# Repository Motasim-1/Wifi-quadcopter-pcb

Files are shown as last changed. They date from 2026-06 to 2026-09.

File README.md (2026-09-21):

# WiFi-Controlled Quadcopter PCB Using ESP32

Custom PCB design for a WiFi-controlled quadcopter based on the ESP32 microcontroller. The board was designed in KiCad, assembled using solder paste and a reflow oven, and tested with four motor outputs controlled through a mobile app.

## Project overview

The goal of this project was to design a compact quadcopter control PCB that integrates the main electronics on a single board and reduces external wiring.

## Key features

- ESP32-based control board with built-in WiFi capability
- Custom quadcopter-shaped PCB designed in KiCad
- Four motor-control outputs using MOSFET driver stages
- USB interface for programming/debugging
- SMD assembly using solder paste and reflow oven
- Power verification and short-circuit testing after assembly
- Functional motor testing using mobile-app WiFi control

## Hardware design

The KiCad project is located in:

```text
hardware/kicad/
```

Included schematic sheets:

```text
my_drone.kicad_sch
mcu.kicad_sch
motor.kicad_sch
power.kicad_sch
usb.kicad_sch
imu.kicad_sch
```

The PCB layout file is:

```text
my_drone.kicad_pcb
```

## Figures

### KiCad 3D view

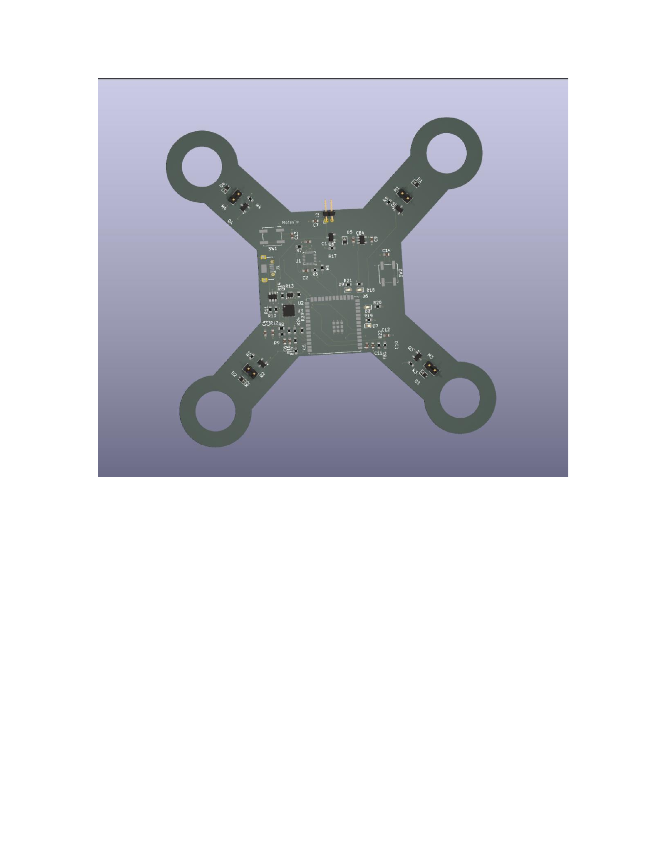
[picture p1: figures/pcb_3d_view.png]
PCB 3D view


### Assembled PCB

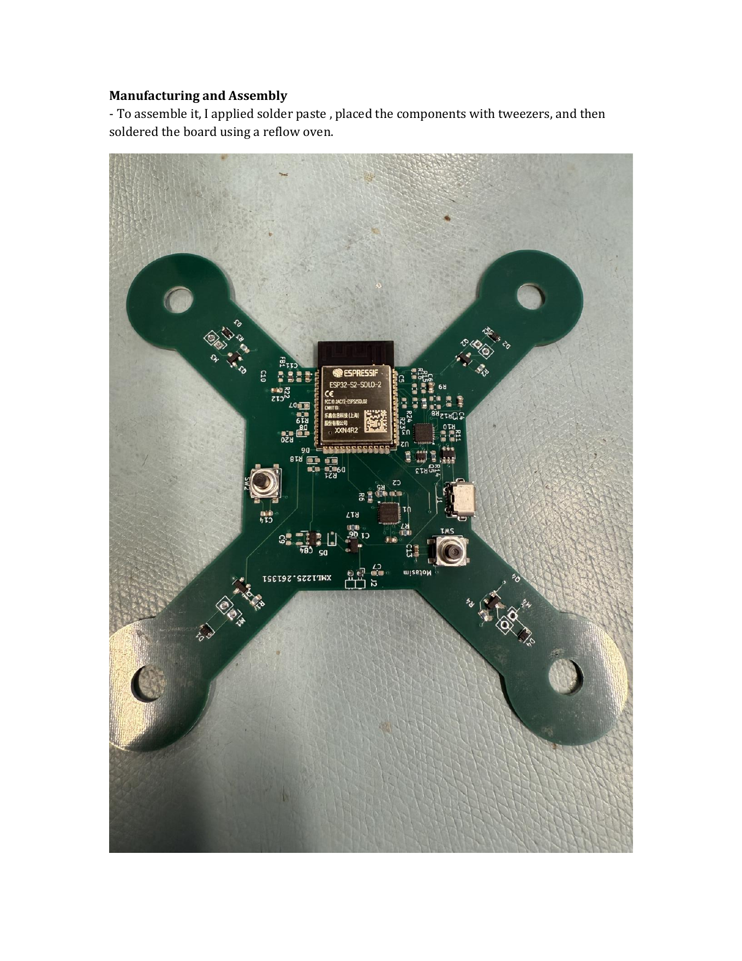
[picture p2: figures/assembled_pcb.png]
Assembled PCB


### Motor test setup

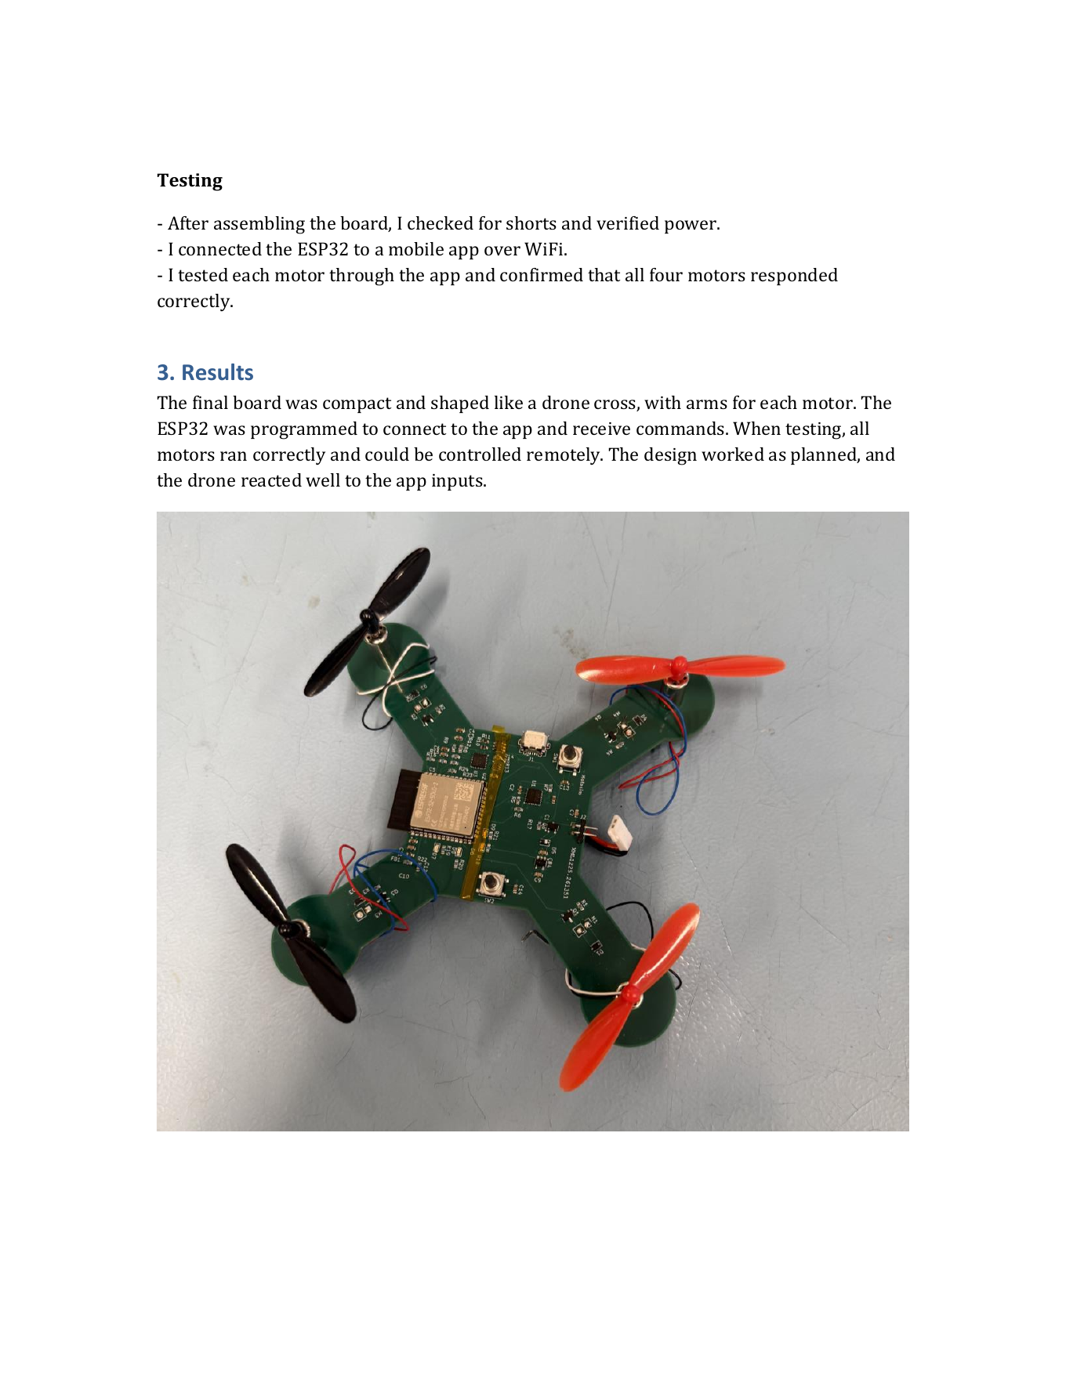
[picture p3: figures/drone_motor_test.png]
Motor test


## Tools and technologies

- KiCad
- ESP32
- PCB design
- SMD soldering
- Reflow soldering
- MOSFET motor switching
- WiFi-based control
- Hardware testing and troubleshooting

## Firmware note

The original motor-control setup was tested using an existing mobile-control framework. This repository focuses on the custom PCB hardware design, assembly and validation. 
## Repository structure

```text
wifi-controlled-quadcopter-pcb/
├── README.md
├── .gitignore
├── hardware/
│   └── kicad/
├── figures/
## Documentation

- [View complete schematic (PDF)](docs/quadcopter_schematic.pdf)

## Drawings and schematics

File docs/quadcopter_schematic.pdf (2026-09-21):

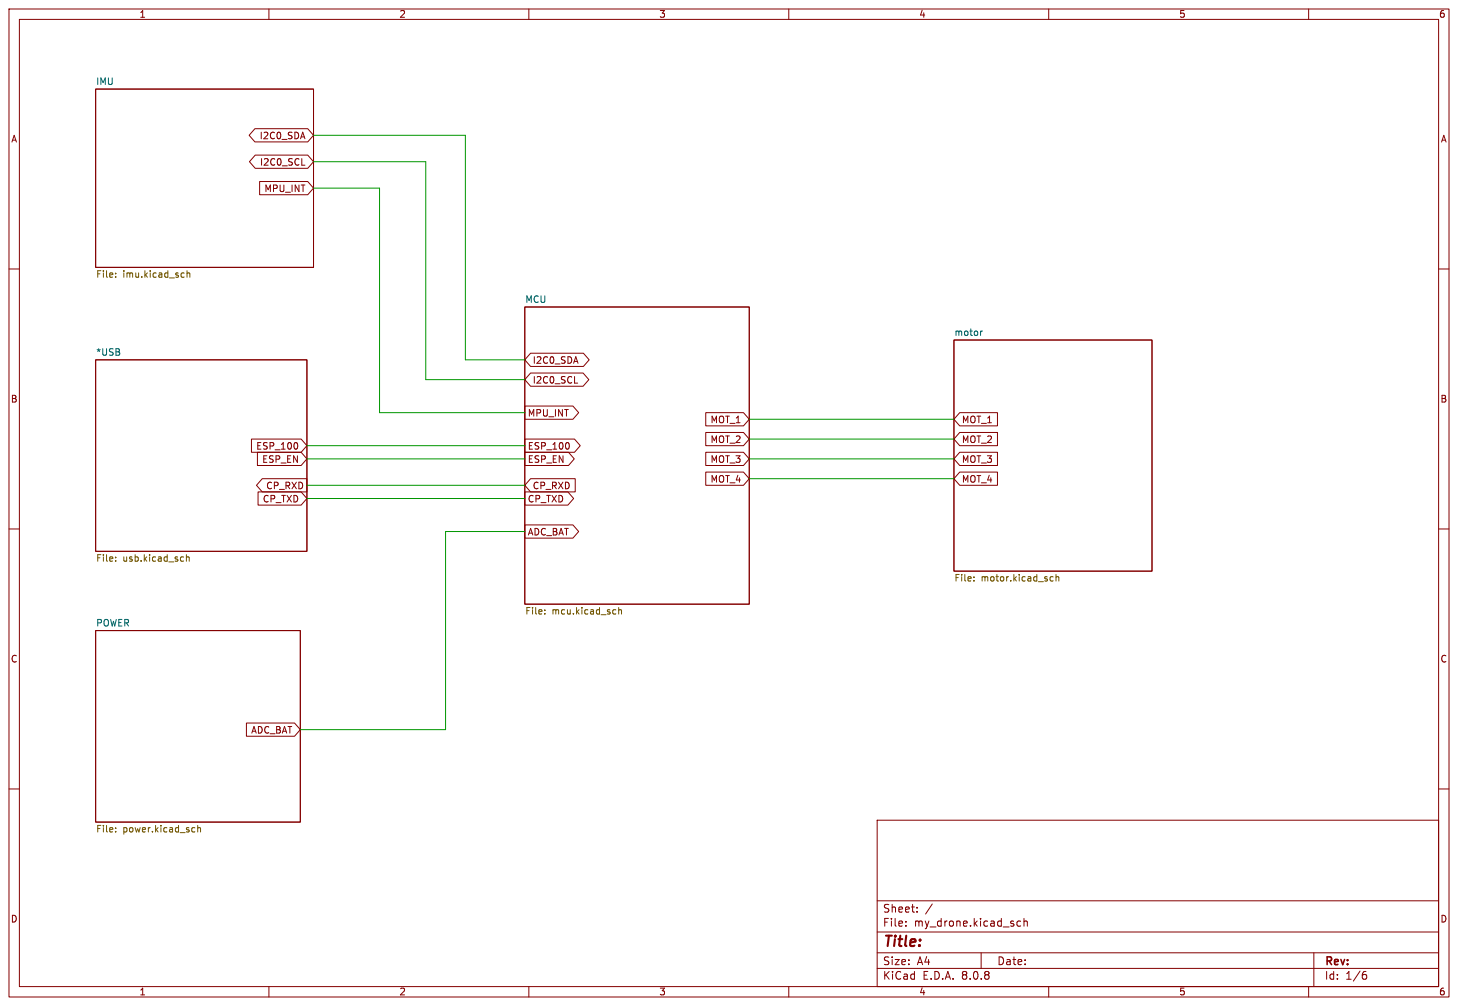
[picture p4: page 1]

Id: 1/6 Title: File: my_drone.kicad_sch Sheet: /

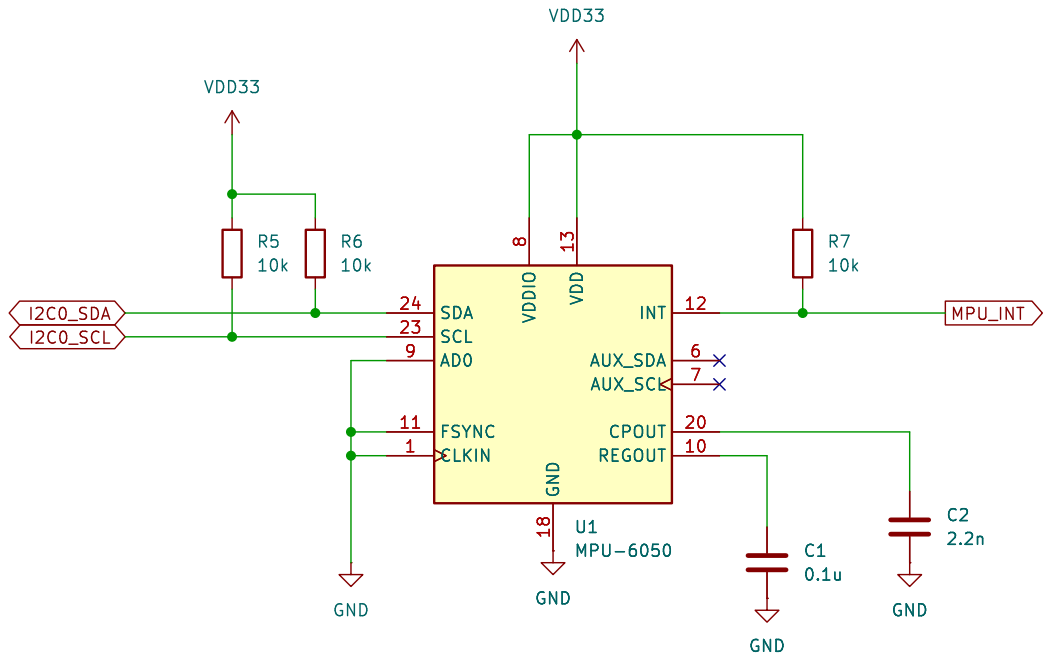
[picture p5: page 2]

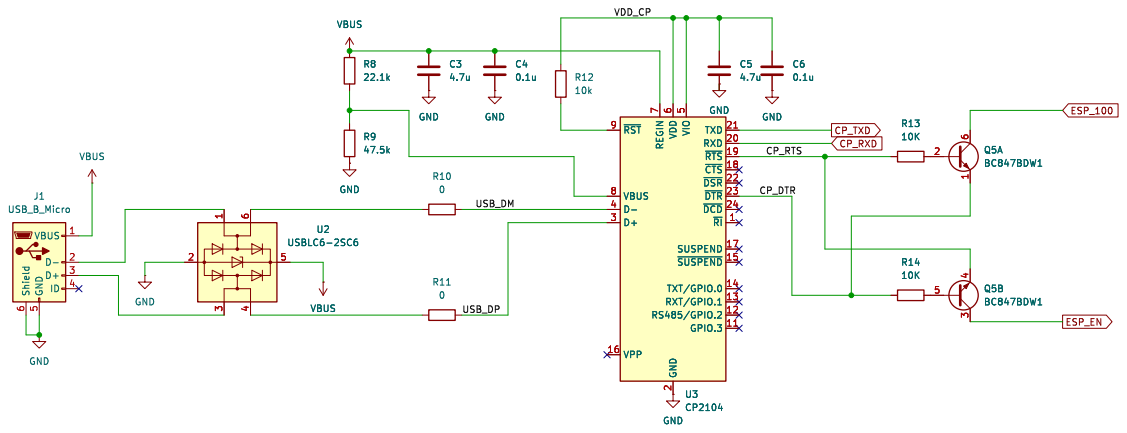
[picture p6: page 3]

7 VBUS 8 ~{RST} 9 GND GND

2 RXD 20 TXD 21 ~{DSR} 22 ~{DTR} 23 ~{DCD} 24 D+ 3 D- 4 VIO

Id: 3/6 Title: File: usb.kicad_sch Sheet: /*USB/

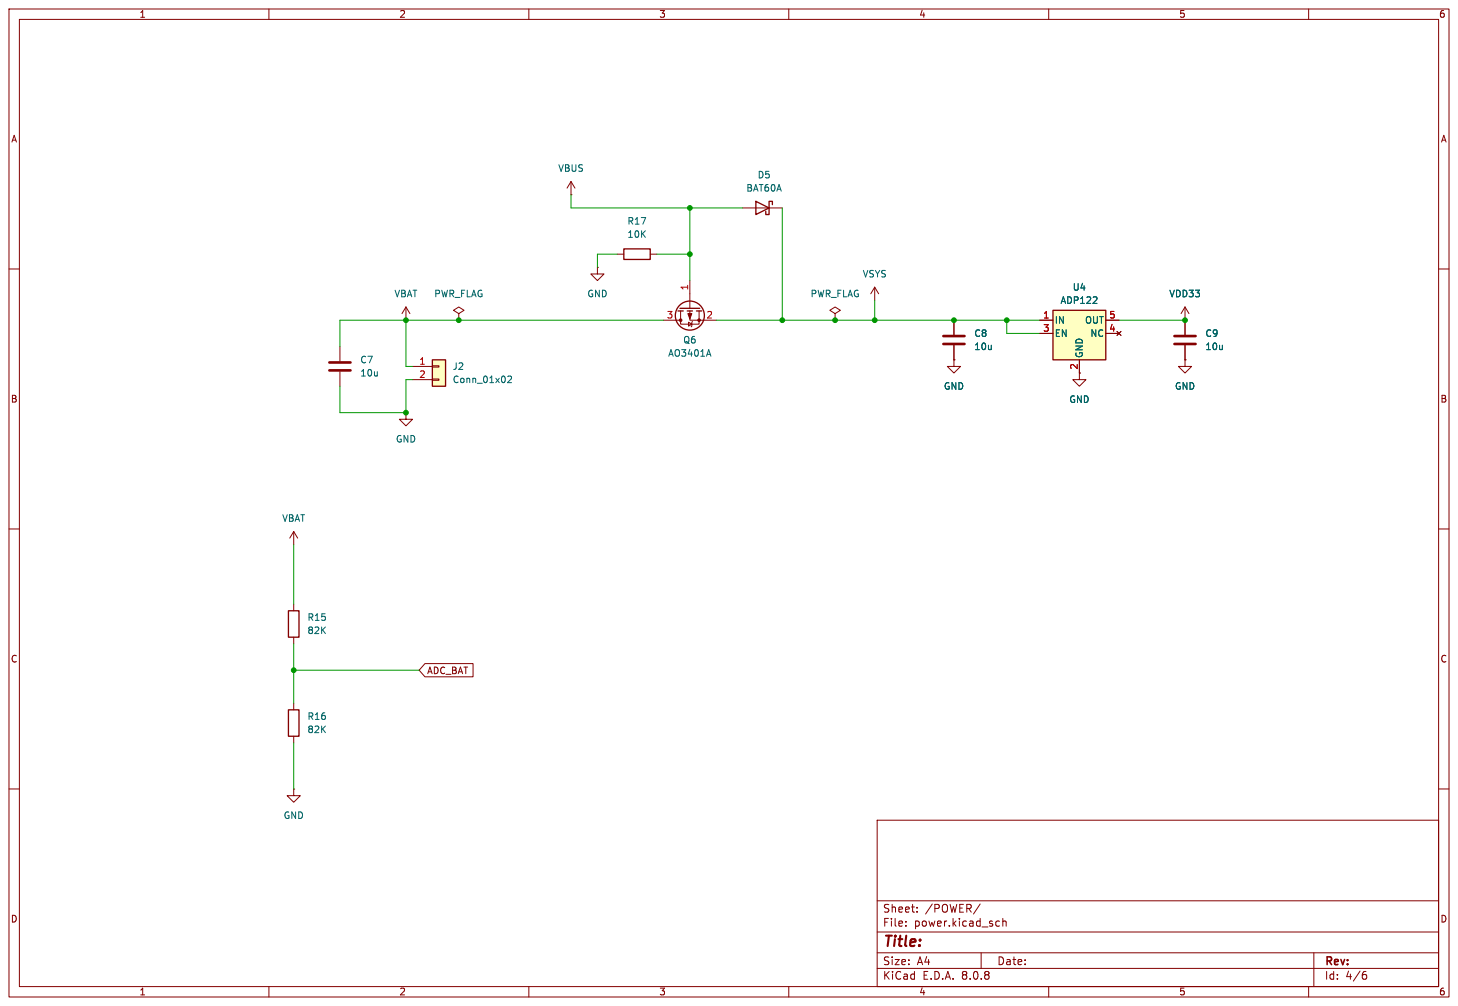
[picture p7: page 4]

2 EN 3 NC 4 OUT 5 U4 ADP122 GND

Id: 4/6 Title: File: power.kicad_sch Sheet: /POWER/

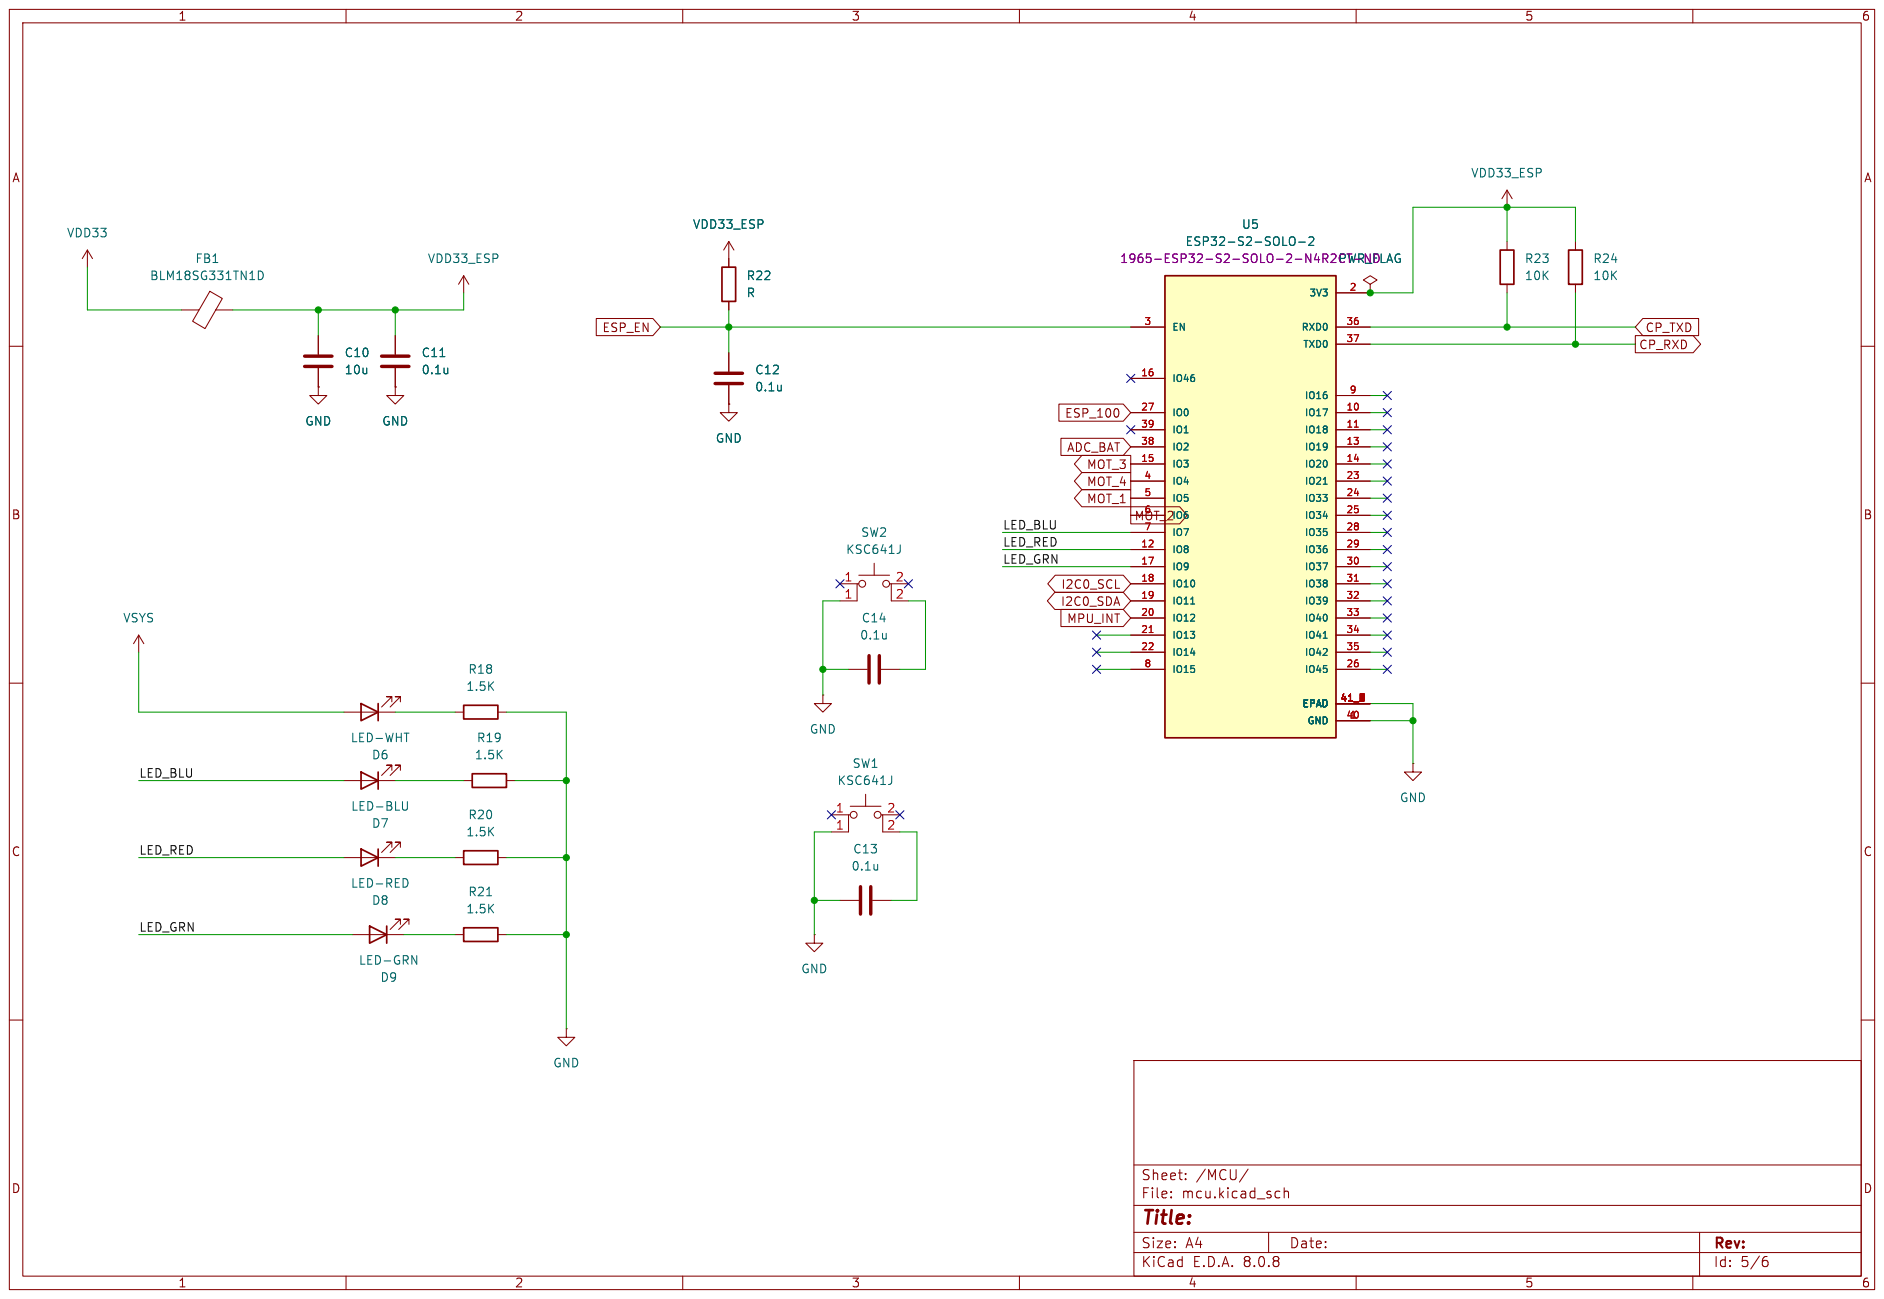
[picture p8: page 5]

Id: 5/6 Title: File: mcu.kicad_sch Sheet: /MCU/ C13

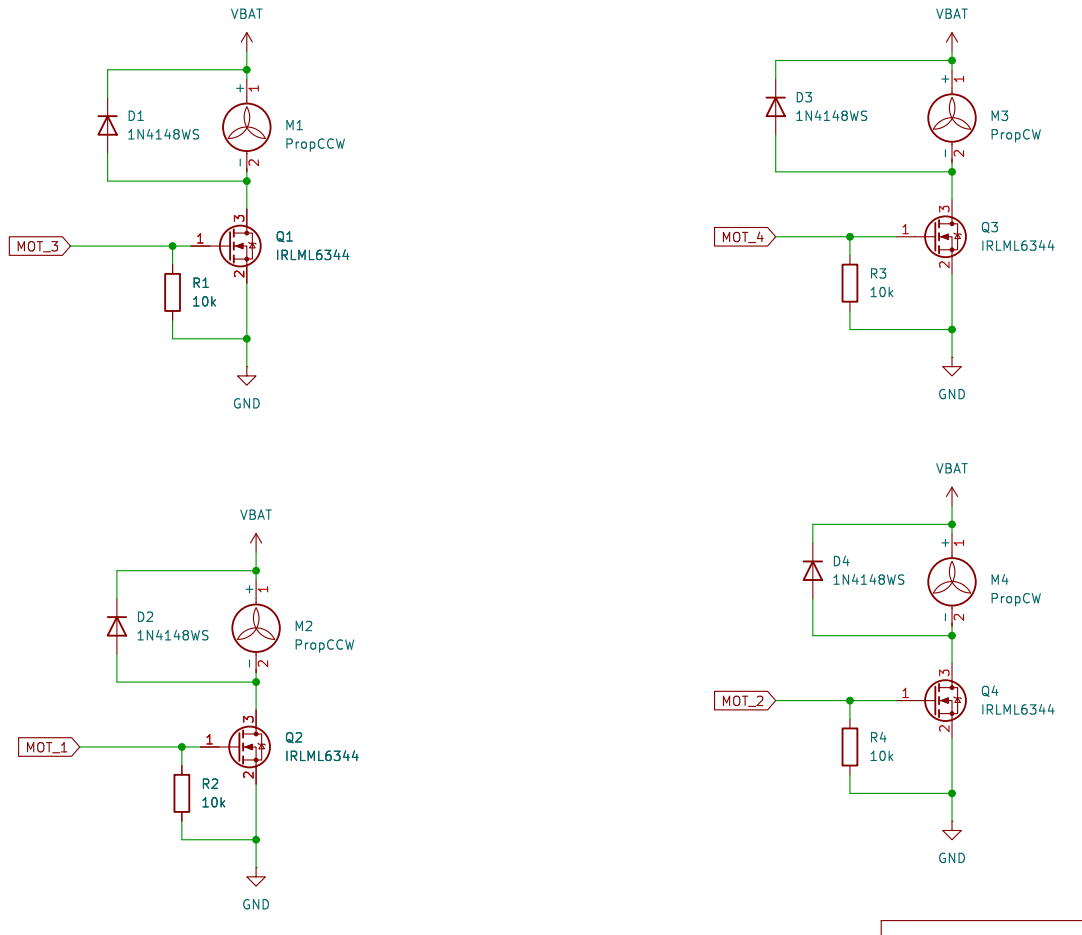
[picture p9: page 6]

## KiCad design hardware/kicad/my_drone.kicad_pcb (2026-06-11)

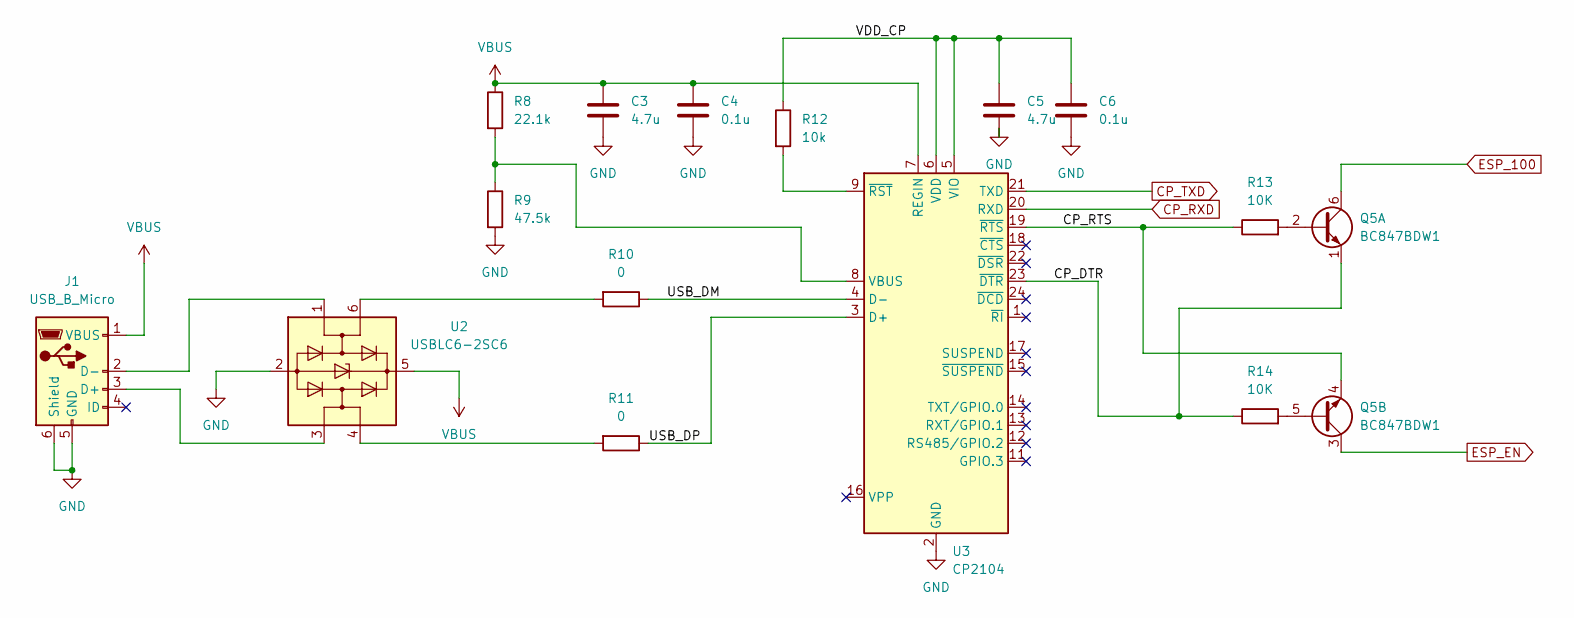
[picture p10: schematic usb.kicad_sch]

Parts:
C3, C5: 4.7u; C_0603_1608Metric
C4, C6: 0.1u; C_0603_1608Metric
J1: USB_B_Micro; USB_Micro
Q5: BC847BDW1; SOT-363_SC-70-6
R8: 22.1k; R_0603_1608Metric
R9: 47.5k; R_0603_1608Metric
R10, R11: 0; R_0603_1608Metric
R12: 10k; R_0603_1608Metric
R13, R14: 10K; R_0603_1608Metric
U2: USBLC6-2SC6; SOT-23-6; Digi-Key 497-5235-1-ND
U3: CP2104; QFN-24-1EP_4x4mm_P0.5mm_EP2.6x2.6mm; Digi-Key 336-4146-1-ND

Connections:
/*USB/CP_DTR: Q5.1 (E1), R14.1, U3.23 (~DTR)
/*USB/CP_RTS: Q5.4 (E2), R13.1, U3.19 (~RTS)
/*USB/USB_DM: R10.1, U3.4 (D-)
/*USB/USB_DP: R11.1, U3.3 (D+)
/*USB/VDD_CP: C5.1, C6.1, R12.1, U3.5 (VIO), U3.6 (VDD)
CP_RXD: U3.20 (RXD); also elsewhere on the board
CP_TXD: U3.21 (TXD); also elsewhere on the board
ESP_100: Q5.6 (C1); also elsewhere on the board
ESP_EN: Q5.3 (C2); also elsewhere on the board
GND: C3.2, C4.2, C5.2, C6.2, J1.5 (GND), J1.6 (Shield), R9.2, U2.2 (GND), U3.2 (GND), U3.25 (GND); also elsewhere on the board
unnamed: J1.3 (D+), U2.3 (I/O2)
unnamed: J1.2 (D-), U2.1 (I/O1)
unnamed: Q5.2 (B1), R13.2
unnamed: Q5.5 (B2), R14.2
unnamed: R10.2, U2.6 (I/O1)
unnamed: R11.2, U2.4 (I/O2)
unnamed: R8.2, R9.1, U3.8 (VBUS)
unnamed: R12.2, U3.9 (~RST)
VBUS: C3.1, C4.1, J1.1 (VBUS), R8.1, U2.5 (VBUS), U3.7 (REGIN); also elsewhere on the board

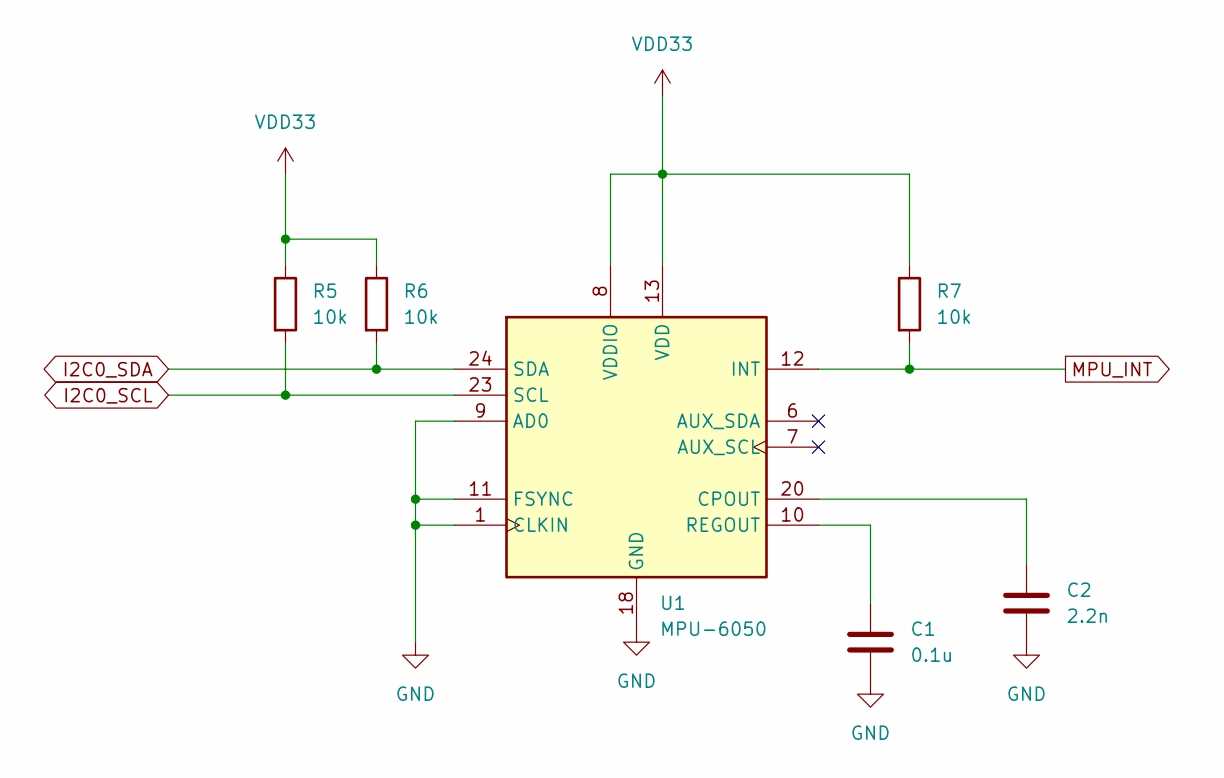
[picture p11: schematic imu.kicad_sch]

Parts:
C1: 0.1u; C_0603_1608Metric
C2: 2.2n; C_0603_1608Metric
R5, R6, R7: 10k; R_0603_1608Metric
U1: MPU-6050; InvenSense_QFN-24_4x4mm_P0.5mm

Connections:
GND: C1.2, C2.2, U1.1 (CLKIN), U1.9 (AD0), U1.11 (FSYNC), U1.18 (GND); also elsewhere on the board
I2C0_SCL: R5.2, U1.23 (SCL); also elsewhere on the board
I2C0_SDA: R6.2, U1.24 (SDA); also elsewhere on the board
MPU_INT: R7.2, U1.12 (INT); also elsewhere on the board
unnamed: C2.1, U1.20 (CPOUT)
unnamed: C1.1, U1.10 (REGOUT)
VDD33: R5.1, R6.1, R7.1, U1.8 (VDDIO), U1.13 (VDD); also elsewhere on the board

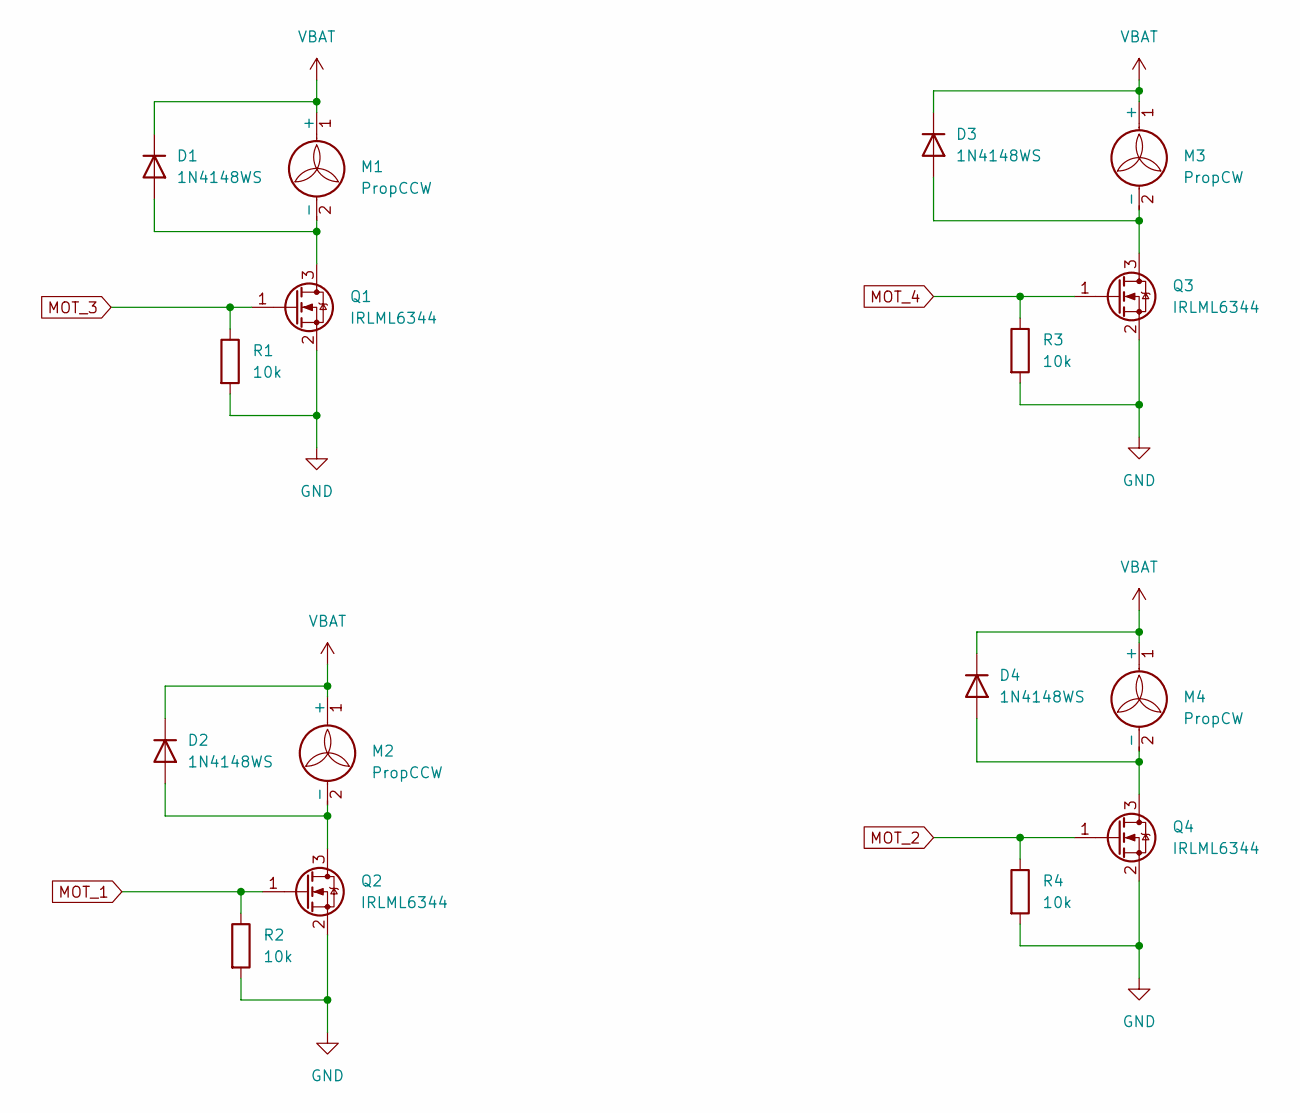
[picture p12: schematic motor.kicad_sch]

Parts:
D1, D2, D3, D4: 1N4148WS; D_SOD-323
M1, M2: PropCCW; PinHeader_1x02_P2.54mm_Vertical
M3, M4: PropCW; PinHeader_1x02_P2.54mm_Vertical
Q1, Q2, Q3, Q4: IRLML6344; SOT-23; Digi-Key IRLML6344TRPBFCT-ND
R1, R2, R3, R4: 10k; R_0603_1608Metric

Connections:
GND: Q1.2 (S), Q2.2 (S), Q3.2 (S), Q4.2 (S), R1.2, R2.2, R3.2, R4.2; also elsewhere on the board
MOT_1: Q2.1 (G), R2.1; also elsewhere on the board
MOT_2: Q4.1 (G), R4.1; also elsewhere on the board
MOT_3: Q1.1 (G), R1.1; also elsewhere on the board
MOT_4: Q3.1 (G), R3.1; also elsewhere on the board
unnamed: D1.2 (A), M1.2 (-), Q1.3 (D)
unnamed: D2.2 (A), M2.2 (-), Q2.3 (D)
unnamed: D3.2 (A), M3.2 (-), Q3.3 (D)
unnamed: D4.2 (A), M4.2 (-), Q4.3 (D)
VBAT: D1.1 (K), D2.1 (K), D3.1 (K), D4.1 (K), M1.1 (+), M2.1 (+), M3.1 (+), M4.1 (+); also elsewhere on the board

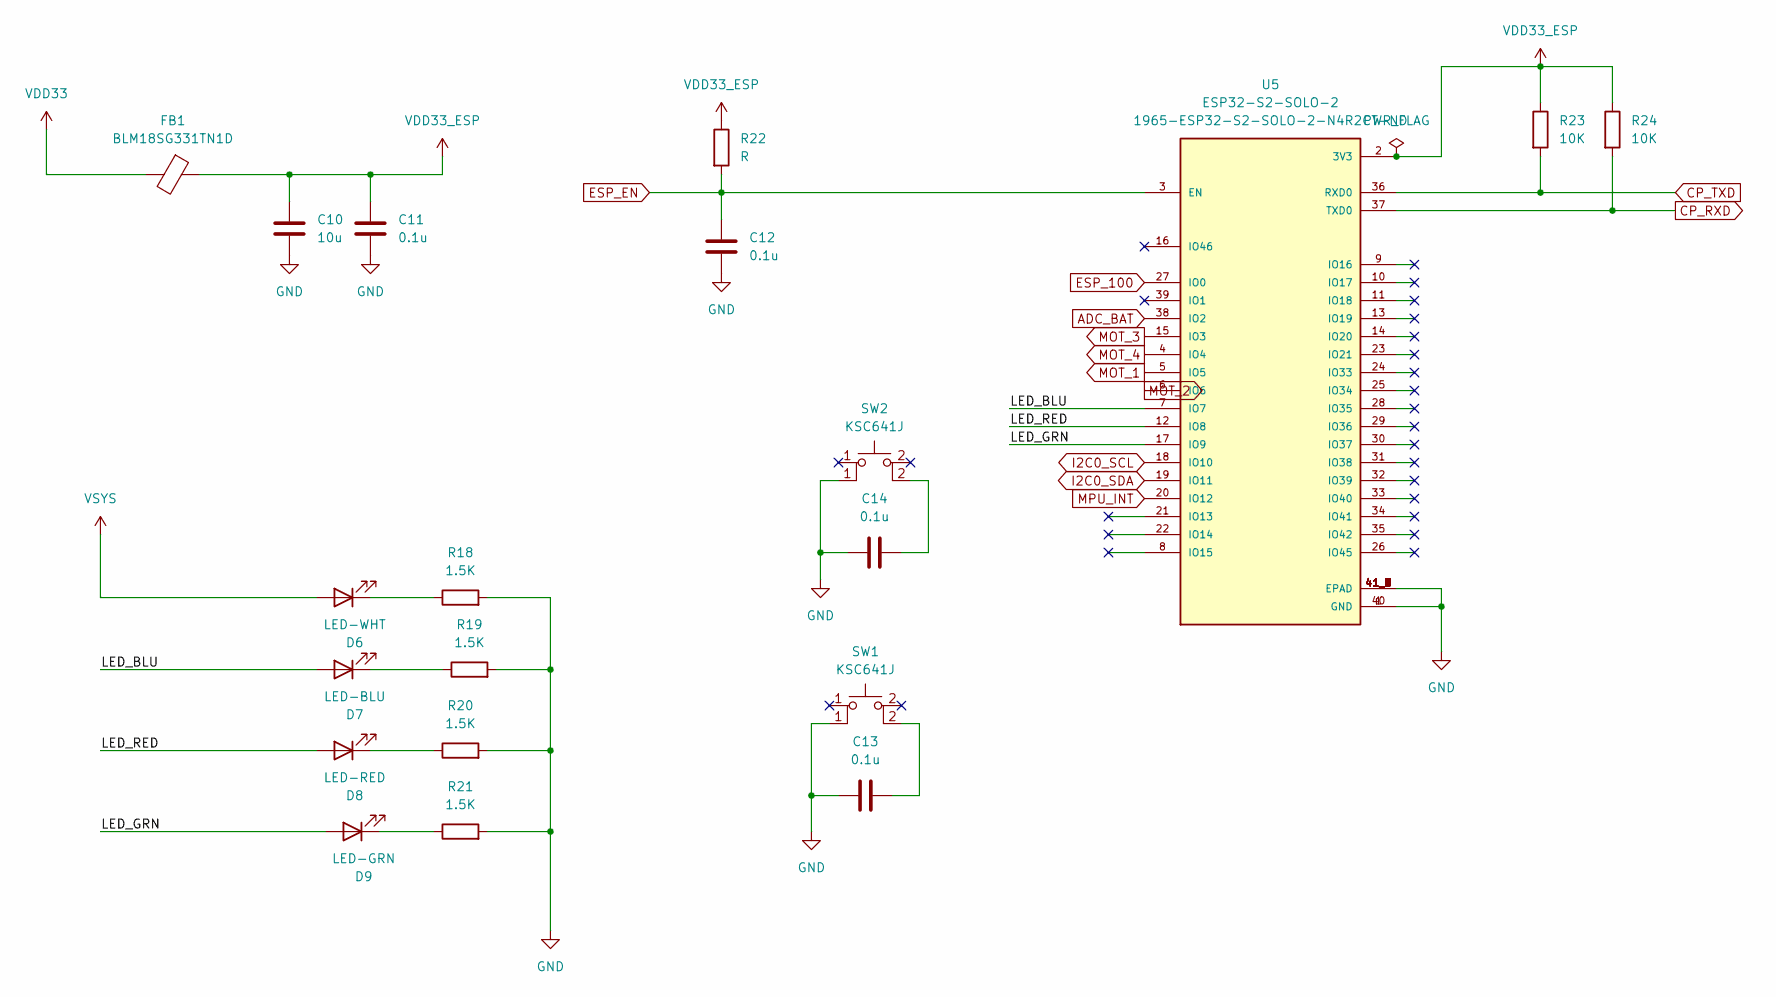
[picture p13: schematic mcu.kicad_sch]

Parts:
C10: 10u; C_0603_1608Metric
C11, C12, C13, C14: 0.1u; C_0603_1608Metric
D6: LED-WHT; LED_0603_1608Metric
D7: LED-BLU; LED_0603_1608Metric
D8: LED-RED; LED_0603_1608Metric
D9: LED-GRN; LED_0603_1608Metric
FB1: BLM18SG331TN1D; R_0603_1608Metric; Digi-Key 490-3997-1-ND
R18, R19, R20, R21: 1.5K; R_0603_1608Metric
R22: R; R_0603_1608Metric
R23, R24: 10K; R_0603_1608Metric
SW1, SW2: KSC641J; SW_Push_1P1T_NO_CK_KSC6xxJ; Digi-Key 401-1788-1-ND
U5: ESP32-S2-SOLO-2; Digi-Key 1965-ESP32-S2-SOLO-2-N4R2CT-ND

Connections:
/MCU/LED_BLU: D7.2 (A), U5.7 (IO7)
/MCU/LED_GRN: D9.2 (A), U5.17 (IO9)
/MCU/LED_RED: D8.2 (A), U5.12 (IO8)
ADC_BAT: U5.38 (IO2); also elsewhere on the board
CP_RXD: R24.2, U5.37 (TXD0); also elsewhere on the board
CP_TXD: R23.2, U5.36 (RXD0); also elsewhere on the board
ESP_100: U5.27 (IO0); also elsewhere on the board
ESP_EN: C12.1, R22.2, U5.3 (EN); also elsewhere on the board
GND: C10.2, C11.2, C12.2, C13.1, C14.1, R18.2, R19.2, R20.2, R21.2, SW1.1 (2), SW2.1 (2), U5.1 (GND), U5.40 (GND), U5.41_1 (EPAD), U5.41_2 (EPAD), U5.41_3 (EPAD), U5.41_4 (EPAD), U5.41_5 (EPAD), U5.41_6 (EPAD), U5.41_7 (EPAD), U5.41_8 (EPAD), U5.41_9 (EPAD); also elsewhere on the board
I2C0_SCL: U5.18 (IO10); also elsewhere on the board
I2C0_SDA: U5.19 (IO11); also elsewhere on the board
MOT_1: U5.5 (IO5); also elsewhere on the board
MOT_2: U5.6 (IO6); also elsewhere on the board
MOT_3: U5.15 (IO3); also elsewhere on the board
MOT_4: U5.4 (IO4); also elsewhere on the board
MPU_INT: U5.20 (IO12); also elsewhere on the board
unnamed: D6.1 (K), R18.1
unnamed: D7.1 (K), R19.1
unnamed: D8.1 (K), R20.1
unnamed: D9.1 (K), R21.1
unnamed: C13.2, SW1.2 (K)
unnamed: C14.2, SW2.2 (K)
VDD33: FB1.2; also elsewhere on the board
VDD33_ESP: C10.1, C11.1, FB1.1, R22.1, R23.1, R24.1, U5.2 (3V3)
VSYS: D6.2 (A); also elsewhere on the board

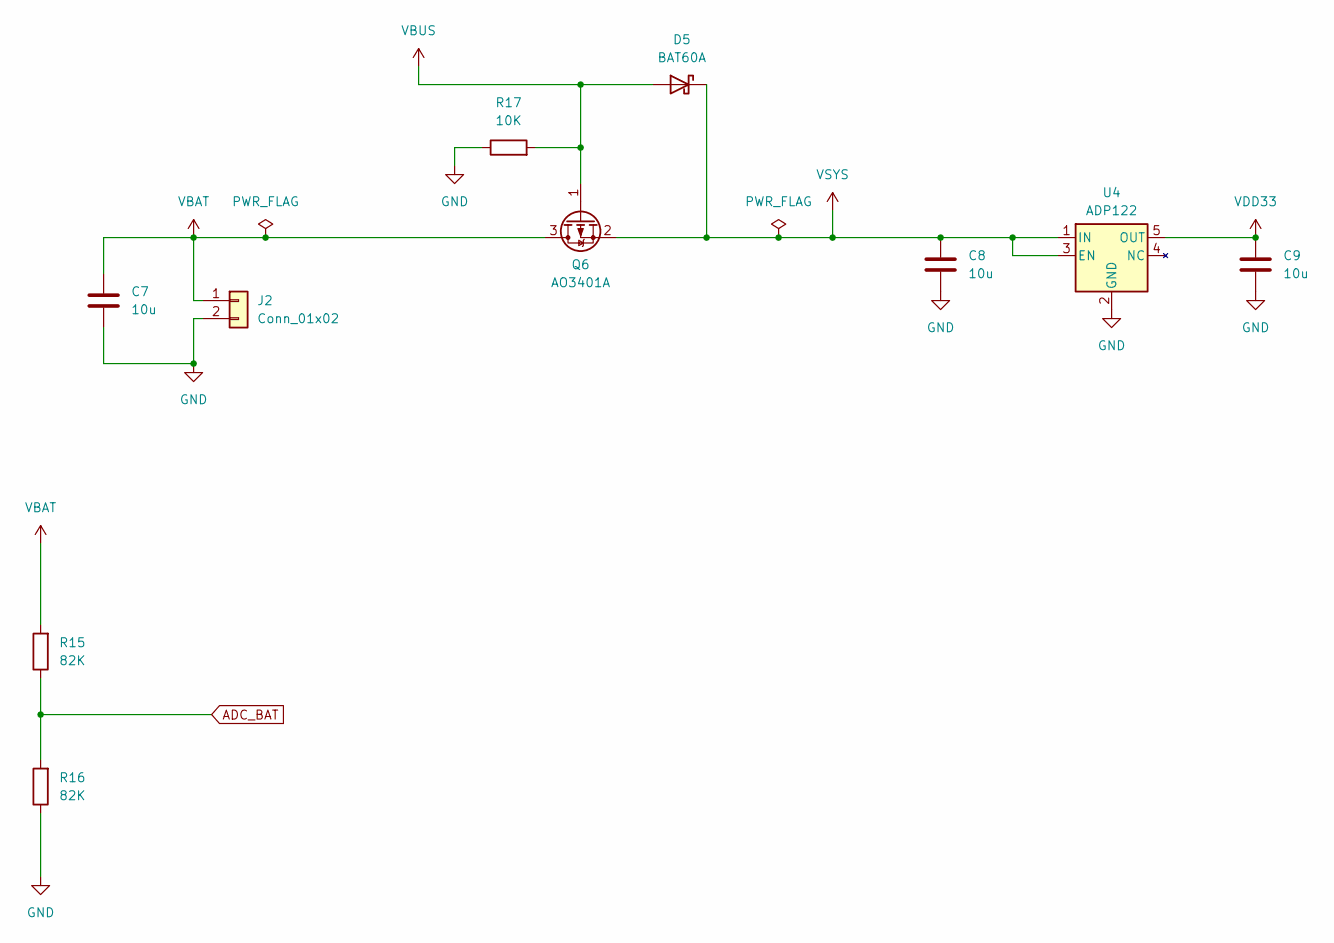
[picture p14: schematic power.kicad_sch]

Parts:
C7, C8, C9: 10u; C_0603_1608Metric
D5: BAT60A; D_SOD-323
J2: Conn_01x02; PinHeader_1x02_P2.00mm_Horizontal
Q6: AO3401A; SOT-23
R15, R16: 82K; R_0603_1608Metric
R17: 10K; R_0603_1608Metric
U4: ADP122; SOT-23-5; Digi-Key 505-ADP122AUJZ-3.3-R7CT-ND

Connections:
ADC_BAT: R15.1, R16.2; also elsewhere on the board
GND: C7.2, C8.2, C9.2, J2.2, R16.1, R17.1, U4.2 (GND); also elsewhere on the board
VBAT: C7.1, J2.1, Q6.3 (D), R15.2; also elsewhere on the board
VBUS: D5.2 (A), Q6.1 (G), R17.2; also elsewhere on the board
VDD33: C9.1, U4.5 (OUT); also elsewhere on the board
VSYS: C8.1, D5.1 (K), Q6.2 (S), U4.1 (IN), U4.3 (EN); also elsewhere on the board

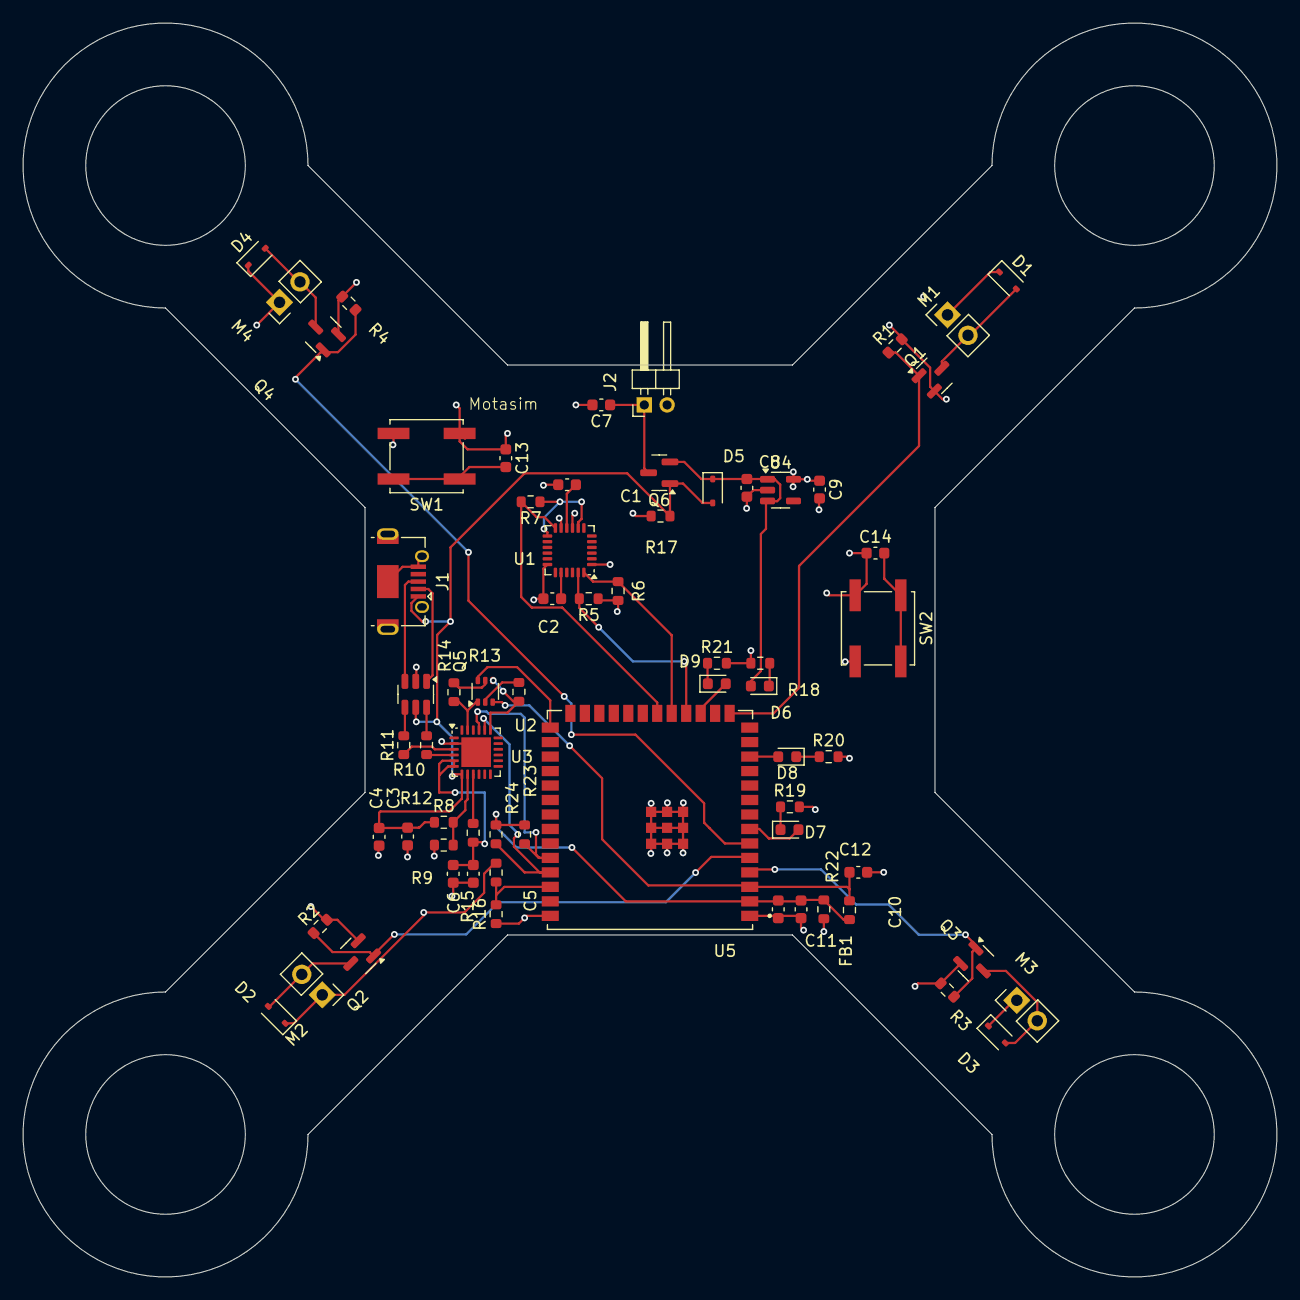
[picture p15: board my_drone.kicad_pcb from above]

Board: 4 copper layers, 110.0 x 110.0 mm, 67 parts (0 on the bottom side), 46 nets.

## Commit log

2026-06-11 drone files
    [imu.kicad_sch, mcu.kicad_sch, motor.kicad_sch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]
2026-09-21 docs: add complete quadcopter schematic PDF
2026-09-21 docs: link schematic PDF from README
